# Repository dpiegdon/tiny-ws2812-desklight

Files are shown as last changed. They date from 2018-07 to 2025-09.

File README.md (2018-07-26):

<!-- vim: fo=a tw=80 colorcolumn=80 syntax=markdown :
-->

ATTiny10-powered WS2812 desklight
=================================

Controller firmware and hardware for a very simple desklight that has a button
and a digital encoder for color/brightness selection.

Controls a strip of WS2812 RGB LEDs which could e.g. be mounted at the bottom
edge of your desktop monitor facing down towards the desk surface.

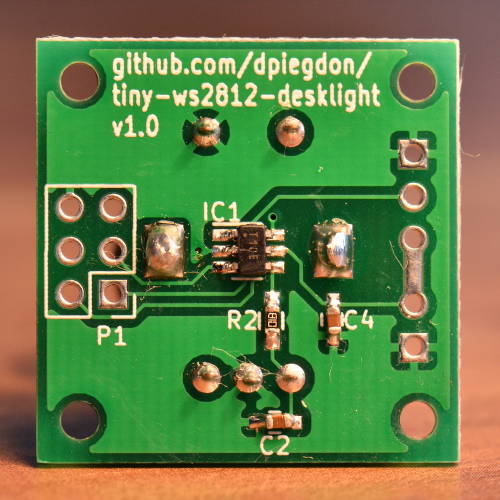
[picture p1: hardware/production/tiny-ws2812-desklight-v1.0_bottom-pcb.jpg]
PCB v1.0 bottom side photo


(Above: bottom side of v1.0 PCB)

Authors
-------

David R. Piegdon <dgit@piegdon.de>

License
-------

All files in this repository are released unter the GNU General Public License
Version 3 or later. This includes the schematic, the routed PCB and the firmware
as well as the documentation and accompanying materials. See the file COPYING
for more information.

Device interface
================

The rotary encoder has a button and can be rotated in both directions. The
button cycles through different modes. In each mode you change a different
variable by rotating the encoder:

* Mode 1: change brightness

* Mode 2: change color

* Mode 3: change number of enabled LEDs

* Mode 4: change starting position of enabled LEDs

Pressing the button for more than half a second resets all values to their
defaults.

Firmware
========

You probably have to use a recent AVR-GCC Version for compilation. Version 5.4.0
is good, 7.3.0 yields even better results. As the ATTiny10 is very
space-constrained, older gcc versions may not optimize well enough to meet the
space-constrains with the current feature set.

If you want to change the number of lights in the firmware, please do so in
`ws2812.h`. If you know what you are doing, you can also change the assignment
to `light_count` in the firmware files (in `ws2812_init()`, `calca_init()`, if
you don't want to recompile.)

Note that with the current <b>master</b> branch firmware you can use up to 126
LEDs. The actual constraint is something like `lightcount <=
max_value(int8_t)-1`.

Firmware Changelog
------------------

### v1.0

Supports four modes (brightness/color/enable-count/start-pos),
should support 63 LEDs. Required GCC 7.3.0 or similar to fit
size-constraints.

### v1.1

Improved binary size. Now supports building with GCC 5.4.0.

### v1.2

Support up to 126 LEDs.

### v1.3

Fixed rotary dial directions to be consistent across modes.

### v1.4

Fixed WS2812 timings to properly work with all LEDs. Allow `LIGHT_COUNT` to be
overriden via `CXXFLAGS`.

### master

(no more changes)

Hardware
========

You can find a Kicad-based schematic in the hardware directory.

The firmware is written for an Atmel ATTiny10. The latest version does not use
the ADC anymore, so an ATTiny9 should do fine, too.

Connect a 5V 1500mA (or better 2000mA) power supply for a strip with 34 LEDs.

Hardware Errata
---------------

### v1.0

Version 1.0 of hardware is <i>fully functional and works perfectly fine</i>.
However, a few changes might be useful when doing another revision:

 * Schematic: Remove comment on questionable 1K resistor value. 1K resistors
   between uC and encoder are ok. Comment in schematic was already removed
   shortly after tag v1.0, as already can be seen in released PDF schematic of
   v1.0.

 * Schematic/BOM: Create a BOM. Well, maybe just specify the kind of rotary
   encoder. (Look for <i>EC11 digital encoder</i> on your favourite cheap
   chinese parts supplier)

 * PCB: Increase drill size for power lines on P2 and P3, so power cables can
   be soldered directly to PCB easily.

 * PCB: Mark RESET pin of TPI so it can be found easily when re-flashing a uC.

 * PCB: Mark TPI interface as "TPI".

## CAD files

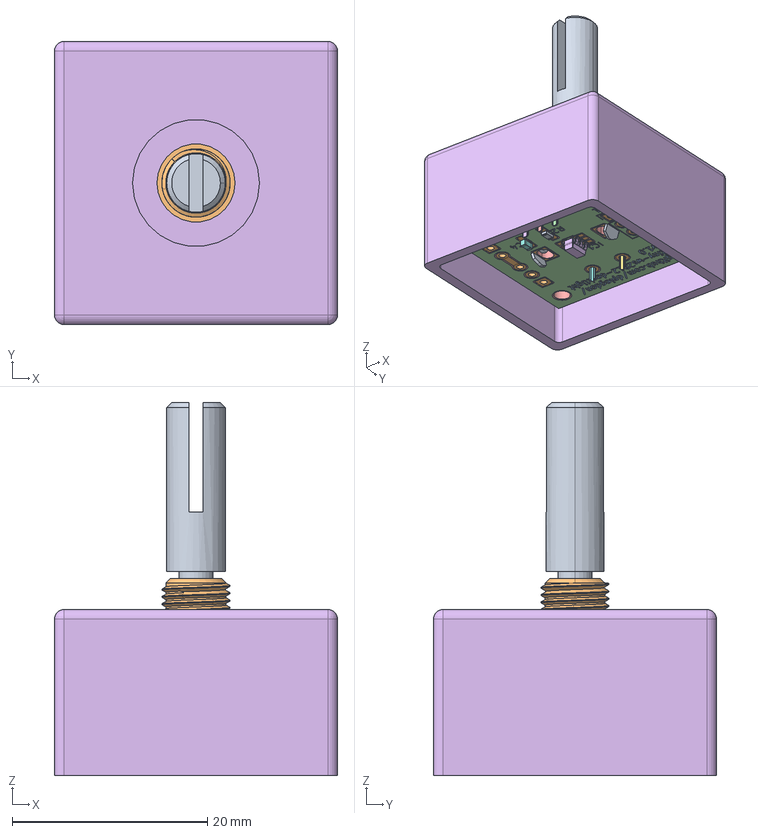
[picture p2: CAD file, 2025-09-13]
hardware/case.FCStd
29.0 x 29.0 x 38.2 mm
Shaft
MetalBody
PlasticBody
Imported
Imported001
Imported002
Pin001
Pin002
Sheet_Metal_Part53
C_0603_1608Metric
C_0603_1608Metric001
R_0603_1608Metric
R_0603_1608Metric001
SOT-23-6
C_0603_1608Metric002
C_0603_1608Metric003
R_0603_1608Metric002
desklight_copper
desklight_silkscreen
desklight_soldermask
desklight_PCB

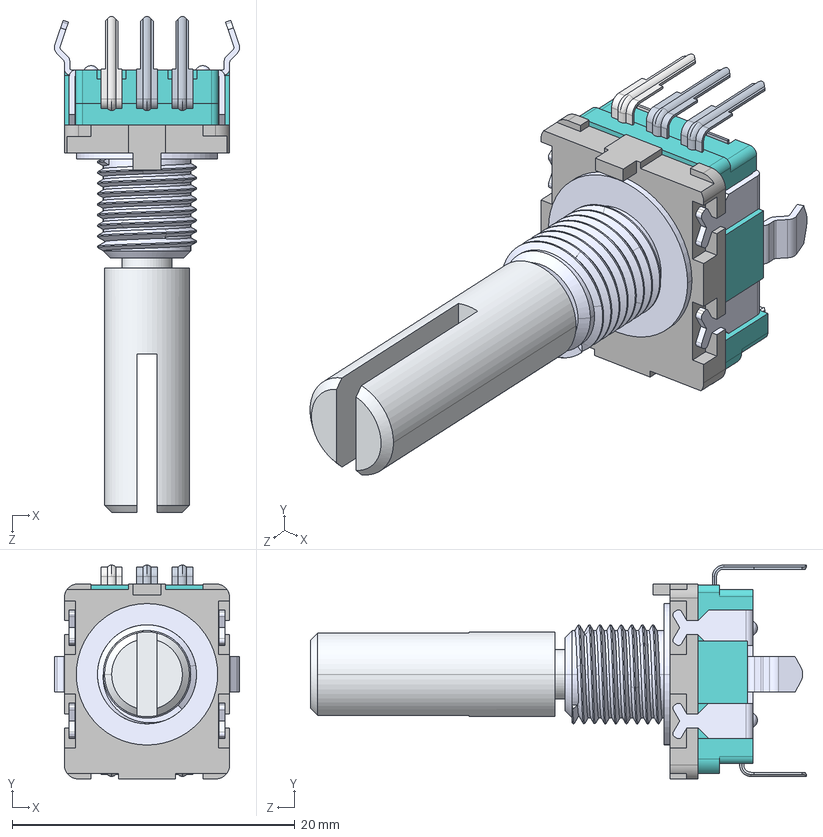
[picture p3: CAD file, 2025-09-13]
hardware/EC11.STEP
13.1 x 15.1 x 35.1 mm
Shaft
MetalBody
PlasticBody
Imported
Imported001
Imported002
Pin001 x 2
Sheet_Metal_Part53

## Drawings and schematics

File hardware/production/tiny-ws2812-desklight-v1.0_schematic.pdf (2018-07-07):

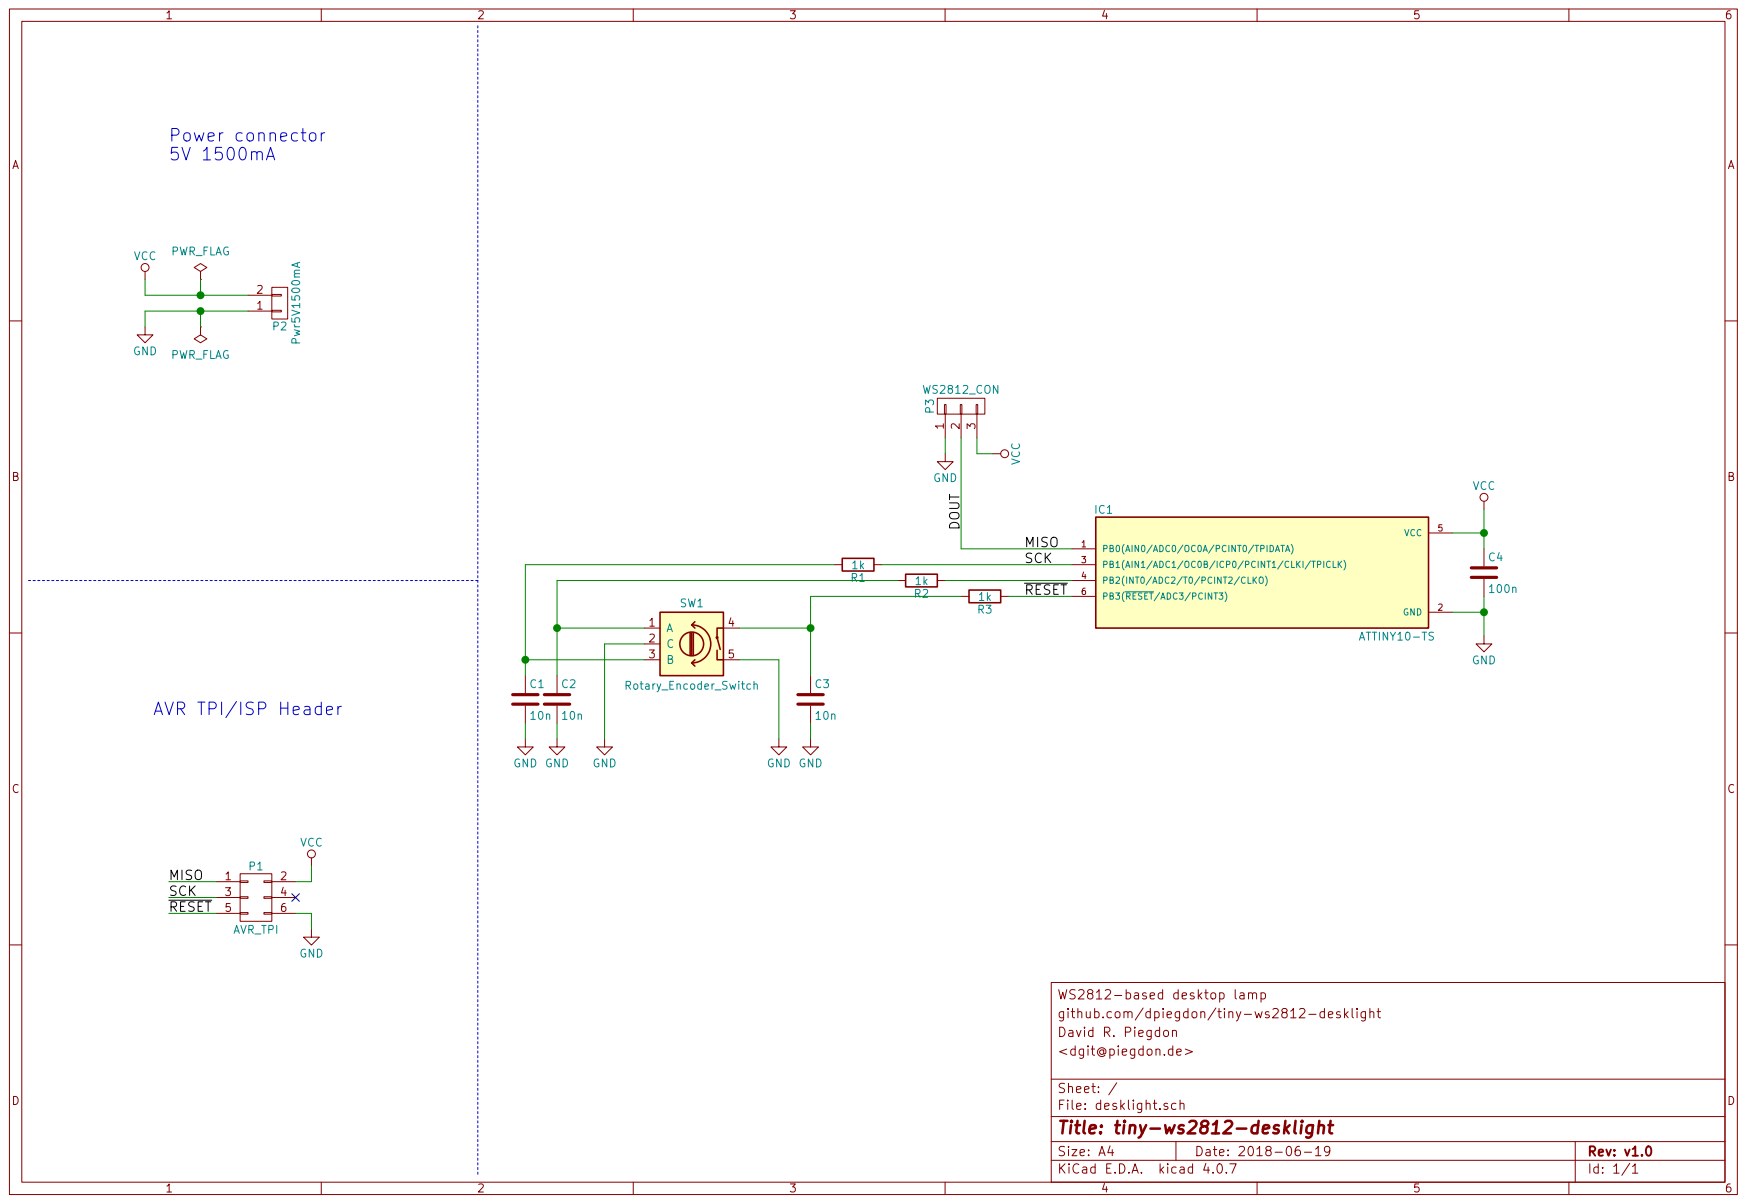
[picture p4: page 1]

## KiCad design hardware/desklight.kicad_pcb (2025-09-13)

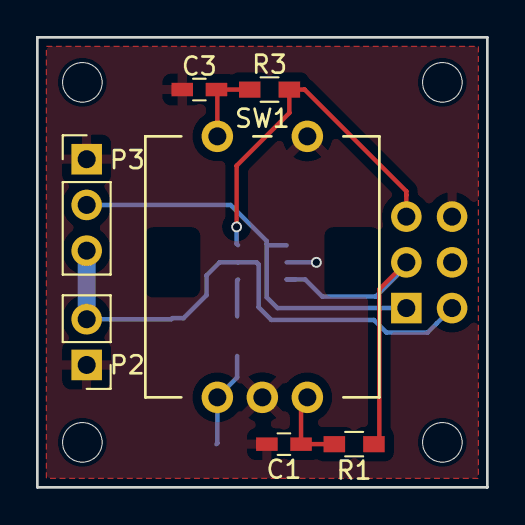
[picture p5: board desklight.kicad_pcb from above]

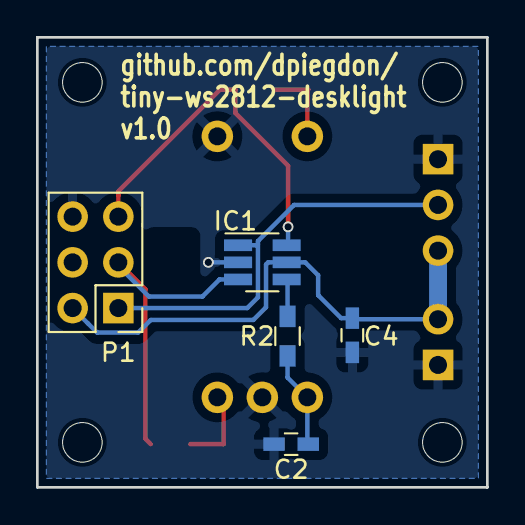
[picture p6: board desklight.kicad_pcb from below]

Board: 2 copper layers, 25.0 x 25.0 mm, 12 parts (5 on the bottom side), 9 nets.

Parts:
C1, C2, C3: C; C_0603_HandSoldering
C4: 100n; C_0603_HandSoldering
IC1: ATTINY10-TS; SOT-23-6_Handsoldering
P1: AVR_TPI; Pin_Header_Straight_2x03_Pitch2.54mm
P2: Pwr5V1500mA; Pin_Header_Straight_1x02_Pitch2.54mm
P3: WS2812_CON; Pin_Header_Straight_1x03_Pitch2.54mm
R1, R2, R3: 1k; R_0603_HandSoldering
SW1: Rotary_Encoder_Switch; Encoder_PEC11R

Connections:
/DOUT: IC1.1, P1.1, P3.2
/SCK: IC1.3, P1.3, R1.1
/~RESET: IC1.6, P1.5, R3.1
GND: C1.2, C2.2, C3.2, C4.2, IC1.2, P1.6, P2.1, P3.1, SW1.2, SW1.5
unnamed: C1.1, R1.2, SW1.3
unnamed: C2.1, R2.2, SW1.1
unnamed: C3.1, R3.2, SW1.4
unnamed: IC1.4, R2.1
VCC: C4.1, IC1.5, P1.2, P2.2, P3.3

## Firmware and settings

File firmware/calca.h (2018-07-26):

#ifndef __CALCA_H__
# define __CALCA_H__

#include "ws2812.h"

#include <avr/interrupt.h>

// this is the same as (((x)*15)/16), but does not require software-multiplication:
#define ATTENUATION(x) ( (((x)<<4) - (x)) / 16 )

// given the above formula using integers, there are this many
// attenuations that are distinct (plus one, which is NO attenuation '0')
#define MAX_ATTENUATION 53

static inline uint8_t decode_colormask(uint8_t mask)
{
	uint8_t ret = mask << 6;
	if(ret == 192)
		ret = 255;
	return ret;
}

static uint8_t get_channel_brightness(uint8_t channelmask, uint8_t current_attenuation)
{
	uint16_t val = decode_colormask(channelmask);
	while(current_attenuation--)
		val = ATTENUATION(val);
	return val;
}

enum calca_modes {
	MODE_ATTENUATION = 0,
	MODE_COLOR = 1,
	MODE_SPOTWIDTH = 2,
	MODE_SPOTPOS = 3,
	MODECOUNT = 4,
};

static uint8_t calca_mode;
static uint8_t calca_color;
static int8_t calca_attenuation;
static uint8_t calca_pos;
static uint8_t calca_width;

static uint8_t light_count;

static void calca_set_new_values(void)
{
	uint8_t r = get_channel_brightness(calca_color >> 0, calca_attenuation);
	uint8_t g = get_channel_brightness(calca_color >> 2, calca_attenuation);
	uint8_t b = get_channel_brightness(calca_color >> 4, calca_attenuation);

	uint8_t calca_offpos = calca_pos + calca_width;
	uint8_t head_on = (calca_offpos > light_count) ? (calca_offpos % light_count) : 0;
	int8_t head_off = calca_pos - head_on;
	int8_t tail_on = calca_width - head_on;
	int8_t tail_off = light_count - head_on - head_off - tail_on;

	cli();
	{
		int8_t i;

		for(i = head_on; i > 0; --i)
			ws2812_set_single(r, g, b);

		for(i = head_off; i > 0; --i)
			ws2812_set_single(0, 0, 0);

		for(i = tail_on; i > 0; --i)
			ws2812_set_single(r, g, b);

		for(i = tail_off; i > 0; --i)
			ws2812_set_single(0, 0, 0);
	}
	sei();
}

#ifndef LIGHT_COUNT
# define LIGHT_COUNT 34
#endif
#if LIGHT_COUNT > 126
# error Only <= 126 lights are supported
#endif

static void calca_init(void)
{
	light_count = LIGHT_COUNT;
	ws2812_init();

	calca_mode = MODE_ATTENUATION;
	calca_color = 0x3;
	calca_attenuation = MAX_ATTENUATION-1;
	calca_pos = 0;
	calca_width = light_count;

	calca_set_new_values();
}

static inline void calca_button(void)
{
	calca_mode++;
	calca_mode %= MODECOUNT;
}

static int8_t check_bounds(int8_t value, int8_t lower, int8_t higher)
{
	return (value < lower) ? lower :
		(value > higher) ? higher :
		value;
}

static inline void calca_rotary_step(int8_t dir)
{

	switch(calca_mode) {
		case MODE_ATTENUATION:
			calca_attenuation = check_bounds(calca_attenuation - dir, 0, MAX_ATTENUATION);
			break;
		case MODE_COLOR:
			calca_color += dir;
			break;
		case MODE_SPOTWIDTH:
			calca_width = check_bounds(calca_width + dir, 1, light_count);
			break;
		default:
		case MODE_SPOTPOS:
			int16_t new_pos;
			new_pos = calca_pos;
			new_pos += light_count;
			new_pos += dir;
			while(new_pos > light_count)
				new_pos -= light_count;
			calca_pos = new_pos;
			break;
	};

	calca_set_new_values();
}

#endif // __CALCA_H__

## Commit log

2017-01-25 sweep, preps for switch and potentiometer
2017-01-27 preps to use ADC for potentiometer
2017-01-27 swap pins for switch and potentiometer to allow power-reduced setup
2017-01-27 fixed sweep code to make sure first LED really has the selected color
2017-01-27 use INT0 for switch, deeper sleep mode
2017-01-28 clock down for powersaving; only update if actual r/g/b values change.
2017-01-28 added schematic, directory layout refactored
    [desklight.kicad_pcb, desklight.sch]
2017-01-29 reduce flickering: hardware improvement, IIR filter for ADC; use more dynamic of potentiometer
    [desklight.sch]
2017-01-31 disable unneeded Timer0; readme: ideas
2017-03-17 initial refactor and preps for encoder use
    [desklight.sch]
2017-03-18 refactor/changes for rotary encoder
2017-03-20 fixed multiple bugs, verified function
    [calca.h]
2017-03-20 set fuses to disable RESET, better color spacing, reset settings after long-press
    [calca.h]
2017-03-20 schematic cleanup
    [desklight.sch]
2017-03-22 basic pcb design
    [desklight.kicad_pcb, desklight.sch]
2017-07-14 support selecting a window of LEDs to light up
2017-08-26 add debouncing caps
    [desklight.kicad_pcb, desklight.sch]
2018-06-19 re-routed with cleanup
    [desklight.kicad_pcb]
2018-06-19 re-route in 2.5x2.5cm formfactor.
    [desklight.kicad_pcb]
2018-06-19 added resistors to allow in-circuit programming
    [desklight.kicad_pcb, desklight.sch]
2018-06-19 PCB version 1.0, also panelized in 10x10cm and production-ready zip file for upload to your favourite PCB store.
    [desklight.kicad_pcb, desklight.sch, desklight_panel.kicad_pcb]
2018-06-19 switch firmware to c++17
2018-06-21 Makefile cleanup to properly represent switch to c++
2018-06-22 fix some logic errors
    [calca.h]
2018-06-25 Makefile options for better assembler output
2018-06-25 fix bug where (non-existing) .rodata section was used for data. never use static data on attiny10...
    [calca.h]
2018-07-07 schematic: 1K resistors seem fine
    [desklight.sch]
2018-07-07 added PDF of schematic
2018-07-09 support up to 126 LEDs
2018-07-25 fix rotary interface such that meaning is same for all modes
    [calca.h]
2025-09-13 forward-port PCB to current kicad, include EC11 step model
    [EC11.STEP, desklight.kicad_pcb, desklight.kicad_sch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]
2025-09-13 basic enclosure model
    [case.FCStd]
